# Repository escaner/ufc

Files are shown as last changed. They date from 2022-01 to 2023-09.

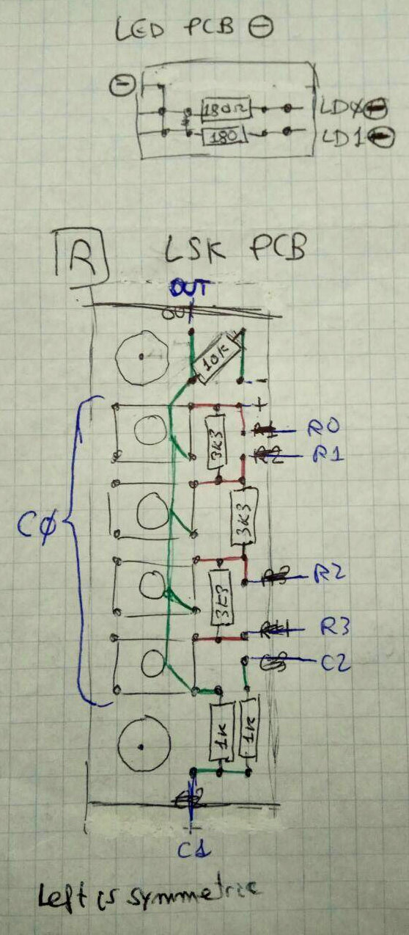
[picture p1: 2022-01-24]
doc/schematics/lsk-led-protobrds.jpg

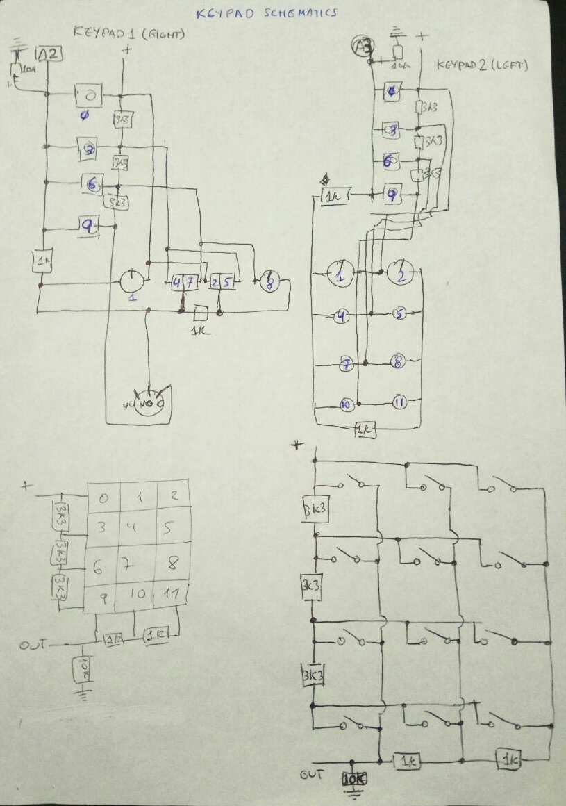
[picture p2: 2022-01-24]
doc/schematics/keypad.jpg

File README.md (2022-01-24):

https://github.com/escaner/ufc

UFC is an Arduino project to interface a button box made of button switches
and rotary encoders, LCD and LEDs, with a computer and identify itself as
a game controller sending DirectX events and communicating also via DCS-BIOS.

The core of the system is a Sparkfun Pro Micro or clone (small Arduino
Micro/Leonardo compatible). The switches are attached directly to the Arduino
analog input grids with resistors, while the encoders are directly attached
to digital pins and managed by the custom made REncoderAsync library.
The Joystick library interfaces with the computer and presents the Arduino
itself as a game controller.

This project requires the following libraries:
* https://github.com/dcs-bios/dcs-bios
* https://github.com/MHeironimus/ArduinoJoystickLibrary
* https://github.com/escaner/REncoder
* https://github.com/escaner/Switch
* https://github.com/fmalpartida/New-LiquidCrystal
* EEPROM

More info can be found in the doc directory, including schematics and
pictures.

Material used (most components were purchased on Aliexpress)
* 3D printer + PLA filament to make the case
* Adhesive vinyl with carbon fiber finish
* Paper printer, paper and glue for labels
* Hot glue gun + glue to stick the Pro Micro and other portoboard assemblies
* Soldering iron, solder, wires and other related tools
* Protoboard for LSK assembly, LED resistors and +/- hubs
* Dupont terminals (optional)
* 1 x USB A-microB cable
* 1 x Pro Micro 5V (Arduino/Sparkfun clone)
* 1 x Robotdyn 4x4 keypad module
* 1 x 2004 LCD display with I2C module
* Resistors for two matrices of buttons: 6 x 3.3K, 4 x 1K, 2 x 10K
* Resistors for LEDs: 2 x 180 Ohm (actual value depends on the LEDs)
* 1 x small momentary pushbutton (the red one)
* 2 x 15mm linear potentiometer 10K + knobs
* 8 x DIP tacile button 10mm 6x6 + 6mm caps
* 4 x rotary encoders with pushbutton + knobs
* 2 x 12mm 3-position momentary switch 3pin (SH T8014A-Z1)
* 6 x 12mm momentary pushbuttons
* 1 x 16mm momentary pushbutton with red LED for 5V
* 2 x 5mm green LEDs + housing
* 19 x M3 screws and nuts, serveral lengths (or saw to trim them!)
* 4 x adhesive rubber feet

To test whether the controller is recognized by a Linux the computer, you can
use the following command:

$ dmesg | grep Joystick

* Use the device name as follows to check the events sent to the computer:
$ jstest /dev/input/js1

Copyright (C) 2021-2022, Óscar Laborda

This file is part of UFC software.

UFC is free software: you can redistribute it and/or modify
it under the terms of the GNU General Public License as published by
the Free Software Foundation, either version 3 of the License, or
(at your option) any later version.

UFC is distributed in the hope that it will be useful,
but WITHOUT ANY WARRANTY; without even the implied warranty of
MERCHANTABILITY or FITNESS FOR A PARTICULAR PURPOSE.  See the
GNU General Public License for more details.

You should have received a copy of the GNU General Public License
along with UFC.  If not, see <https://www.gnu.org/licenses/>.

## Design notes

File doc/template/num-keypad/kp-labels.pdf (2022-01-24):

1

T-ILS

+

ABC SYS

2
N

ALOW

DEF NAV

3

+

GHI WP

4
W

STPT

JKLOSET

5

CRUS

MNOFPM

6
E

TIME

PQR PRV

7

MARK

STUFPLN

8
S

FIX

VWXMRK

9

A-CAL

YZ MSN

0

M-SEL · STEER

# CLR

MALF

# ENT

A/P

## IFF

## FUNC

## TCN

## LIST

## LTR

# A-AS

A-G

+
ON

A-G

SPCWPT

A-G

+

## ILS

A-A

MKUPDT

HCKPOS

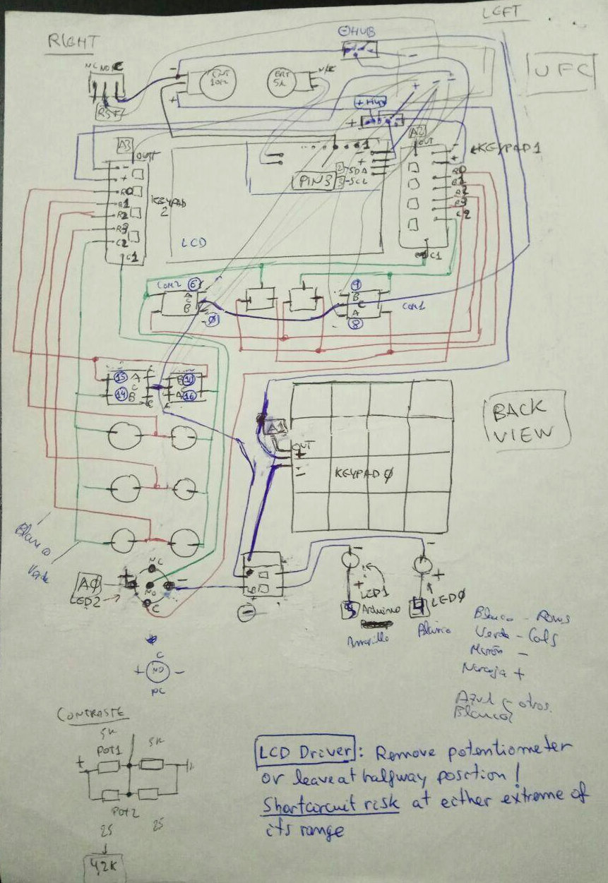
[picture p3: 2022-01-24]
doc/schematics/ufc.jpg

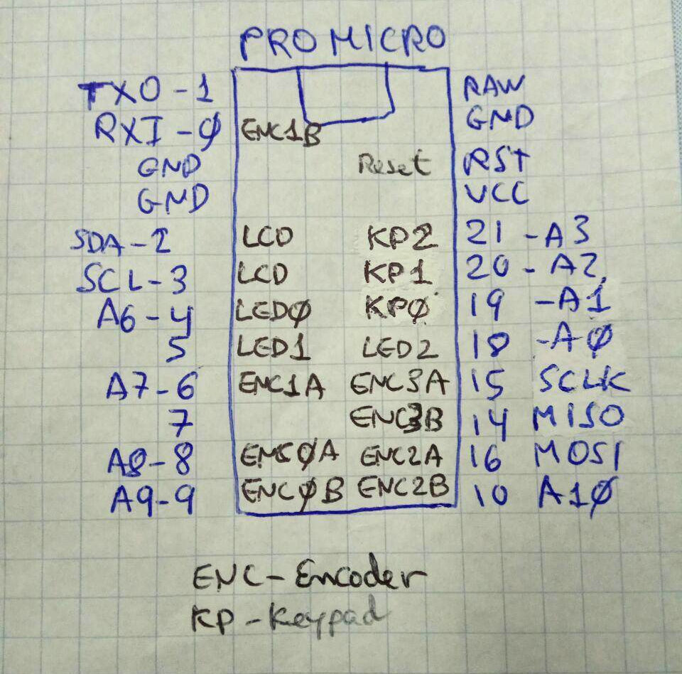
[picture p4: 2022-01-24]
doc/schematics/arduino-promicro.jpg

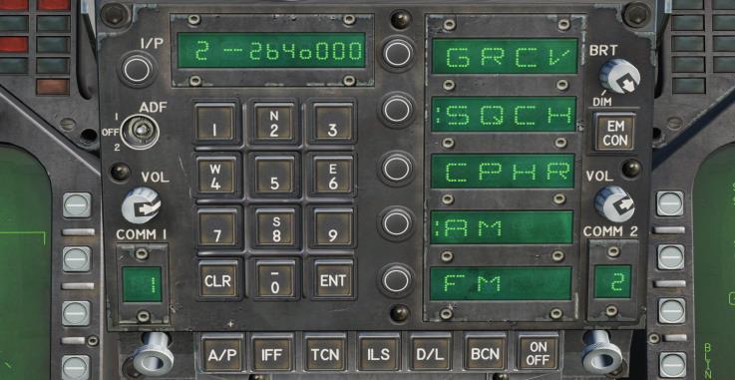
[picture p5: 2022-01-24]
doc/template/num-keypad/f18-ufc.jpg

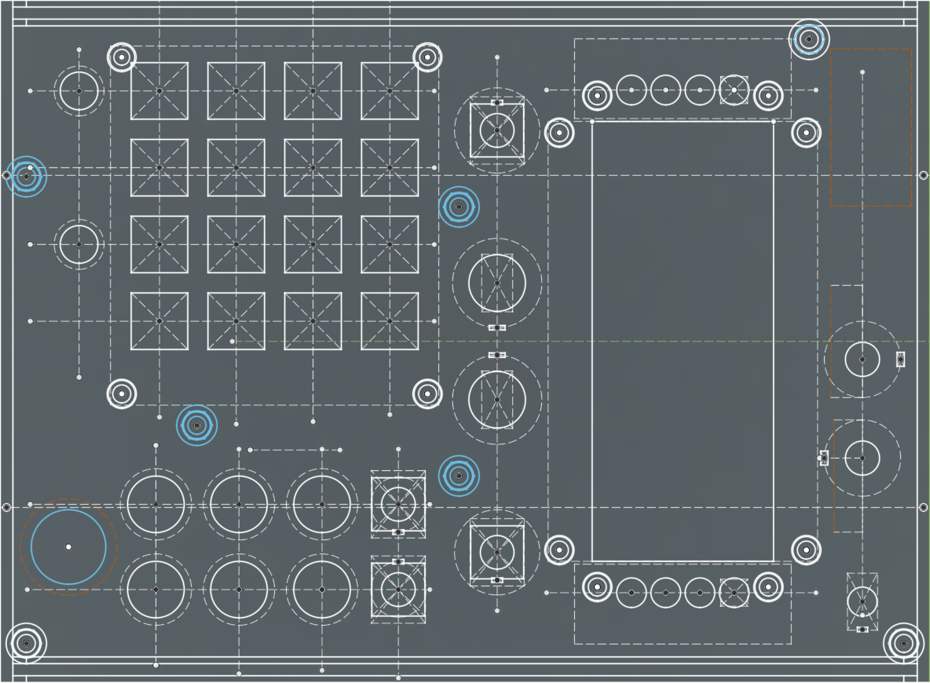
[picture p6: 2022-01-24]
doc/template/labels/shape.png

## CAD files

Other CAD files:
doc/case/ufc-panel.f3d

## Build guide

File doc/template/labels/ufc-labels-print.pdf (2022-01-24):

RESET

A

B

OP4

OP5

CDU LSK

IFEI

FCR

IFEI

CEN

CPL

OP1

OP2

OP3

IFEI

CDU LSK
HSD

MODE

## A-10 F/A-18

F-16 M2000

## COM1

## UHF⚫ HDG HDG

## FUEL QTY

HDG | CRS
DATA | SEL QTY | DIST
PG | -+
A/P | ALT HLD | ALT SEL APP

EFF INS

## MASTER ARM

## LST/R GUN RDY

## CAT I

## COM2

## ⚫V/UHF CRS CRS

WPT
SEQ

STEER
PTR

WPT

SEQ

VAD MODE

## CAUTION

TCN
TCN

NAV M

ILS
ILS

COM1

AUTO
ANCHR

DEC

WPT
STRPT

VISU

WPDSG

ALT
ALRT

A
MK

COM2

ENT

NORM WING

S T O R E S

1 2 3

DEST

REC

MRC

PREP

BAD

VAL

RANGE

RET

VAD -+ | VAD MODE

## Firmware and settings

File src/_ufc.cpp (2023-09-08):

#define DCSBIOS_DEFAULT_SERIAL

#include <stdint.h>
#include <EEPROM.h>
#include <Joystick.h>
#include <DcsBios.h>
#include "config.h"
#include "mode.h"
#include "switchpnl.h"
#include "displpnl.h"
#include "directx.h"


/*******************/
/* Local constants */
/*******************/

// Number of iterations processing switches per loop() call
constexpr uint16_t SWITCH_LOOP_CNT = 150U;

// EEPROM address where the default mode is stored
constexpr int EEPROM_MODE_ADDR = 0;


/** PRO MICRO pin connections **/

constexpr uint8_t PIN_LCD_EN = 2U;
constexpr uint8_t PIN_LCD_RW = 1U;
constexpr uint8_t PIN_LCD_RS = 0U;
constexpr uint8_t PIN_LCD_D4 = 4U;
constexpr uint8_t PIN_LCD_D5 = 5U;
constexpr uint8_t PIN_LCD_D6 = 6U;
constexpr uint8_t PIN_LCD_D7 = 7U;
constexpr uint8_t PIN_LCD_BL = 3U;

static const uint8_t PIN_ENCODER[NUM_ENC][ENC_NUM_PINS] =
{
  {  8,  9 }, // EncCom1
  {  6,  0 }, // EncCom2 (pin 7 does not work in my Pro Micro -> using 0 (RXI))
  { 16, 10 }, // EncLeft
  { 15, 14 }, // EncRight
};
static const uint8_t PIN_KP[NUM_KP] = { A1, A2, A3 };
static const uint8_t PIN_LED[NUM_LED] = { 4, 5, A0 };
// SDA: D2
// SCL: D3


/** Keypad constants **/

// Keypad where to read the mode at boot time
static const uint8_t KP_MODE = 0;


/** LCD **/

constexpr uint8_t LCD_ADDR = 0x27;

static const DisplPnl::LcdData_t LcdData =
{
  LCD_ADDR,
  PIN_LCD_EN,
  PIN_LCD_RW,
  PIN_LCD_RS,
  PIN_LCD_D4,
  PIN_LCD_D5,
  PIN_LCD_D6,
  PIN_LCD_D7,
  PIN_LCD_BL,
  POSITIVE
};


/* DCS-BIOS */

// Used in DCS BIOS messages in several modules
static const char _BIOS_MSG_HDG[] PROGMEM = { 'H', 'D', 'G' };
static const char _BIOS_MSG_CRS[] PROGMEM = { 'C', 'R', 'S' };
static const char _BIOS_ARG_INC_CHAR = '+';
static const char _BIOS_ARG_DEC_CHAR = '-';

constexpr uint8_t DCS_ACFTNAME_SZ = 24U;
constexpr unsigned int DCS_ACFTNAME_ADDR = 0x0000;

// A-10C
constexpr uint8_t A10C_CDUSP_SZ = 24U;
constexpr unsigned int A10C_CDUSP_ADDR = 0x1298;
constexpr uint8_t A10C_UHFFREQ_SZ = 7U;
constexpr unsigned int A10C_UHFFREQ_ADDR = 0x1180;
constexpr unsigned int A10C_UHFMODE_ADDR = 0x117c;
constexpr unsigned int A10C_UHFMODE_MASK = 0x0003;
constexpr unsigned int A10C_UHFMODE_SHIFT = 0U;
constexpr uint8_t A10C_UHFPSET_SZ = 2U;
constexpr unsigned int A10C_UHFPSET_ADDR = 0x1188;
constexpr uint8_t A10C_VAMFREQ_SZ = 7U;
constexpr unsigned int A10C_VAMFREQ_ADDR = 0x12de;
constexpr unsigned int A10C_VAMMODE_ADDR = 0x1186;
constexpr unsigned int A10C_VAMMODE_MASK = 0xc00;
constexpr unsigned int A10C_VAMMODE_SHIFT = 10U;
constexpr uint8_t A10C_VAMPSETSW_SZ = 2U;
constexpr unsigned int A10C_VAMPSETSW_ADDR = 0x118a;
constexpr uint8_t A10C_VFMFREQ_SZ = 7U;
constexpr unsigned int A10C_VFMFREQ_ADDR = 0x12e6;
constexpr unsigned int A10C_VFMMODE_ADDR = 0x1194;
constexpr unsigned int A10C_VFMMODE_MASK = 0x0180;
constexpr unsigned int A10C_VFMMODE_SHIFT = 7U;
constexpr uint8_t A10C_VFMPSETSW_SZ = 2U;
constexpr unsigned int A10C_VFMPSETSW_ADDR = 0x1196;
constexpr uint8_t A10C_TCNCHNL_SZ = 4U;
constexpr unsigned int A10C_TCNCHNL_ADDR = 0x1162;
constexpr unsigned int A10C_TCNMODE_ADDR = 0x1168;
constexpr unsigned int A10C_TCNMODE_MASK = 0x000e;
constexpr unsigned int A10C_TCNMODE_SHIFT = 1U;
constexpr uint8_t A10C_ILSFREQ_SZ = 6U;
constexpr unsigned int A10C_ILSFREQ_ADDR = 0x12d8;
constexpr unsigned int A10C_HSIHDG_ADDR = 0x104c;
constexpr unsigned int A10C_HSIHDG_MASK = 0xffff;
constexpr unsigned char A10C_HSIHDG_SHIFT = 0U;
constexpr unsigned int A10C_HSIHDGBUG_ADDR = 0x1052;
constexpr unsigned int A10C_HSIHDGBUG_MASK = 0xffff;
constexpr unsigned char A10C_HSIHDGBUG_SHIFT = 0U;
constexpr unsigned int A10C_HSICRS_ADDR = 0x1054;
constexpr unsigned int A10C_HSICRS_MASK = 0xffff;
constexpr unsigned char A10C_HSICRS_SHIFT = 0U;
constexpr unsigned int A10C_MASTERCAUTLT_ADDR = 0x1012;
constexpr unsigned int A10C_MASTERCAUTLT_MASK = 0x0800;
constexpr unsigned char A10C_MASTERCAUTLT_SHIFT = 11U;
constexpr unsigned int A10C_MASTERARMSW_ADDR = 0x10e8;
constexpr unsigned int A10C_MASTERARMSW_MASK = 0x000c;
constexpr unsigned char A10C_MASTERARMSW_SHIFT = 2U;
constexpr unsigned int A10C_GUNRDYLT_ADDR = 0x1026;
constexpr unsigned int A10C_GUNRDYLT_MASK = 0x8000;
constexpr unsigned char A10C_GUNRDYLT_SHIFT = 15U;

// F-16C
constexpr unsigned int F16C_DED_SZ = 29U;
constexpr unsigned int F16C_DEDLINE1_ADDR = 0x4500;
constexpr unsigned int F16C_DEDLINE2_ADDR = 0x451e;
constexpr unsigned int F16C_DEDLINE3_ADDR = 0x453c;
constexpr unsigned int F16C_DEDLINE4_ADDR = 0x455a;
constexpr unsigned int F16C_DEDLINE5_ADDR = 0x4578;
constexpr unsigned int F16C_FUELQTYKNOB_ADDR = 0x441e;
constexpr unsigned int F16C_FUELQTYKNOB_MASK = 0x0007;
constexpr unsigned char F16C_FUELQTYKNOB_SHIFT = 0U;
constexpr unsigned int F16C_FUELQTYKNOBTST_ADDR = 0x441c;
constexpr unsigned int F16C_FUELQTYKNOBTST_MASK = 0x4000;
constexpr unsigned char F16C_FUELQTYKNOBTST_SHIFT = 14U;
constexpr unsigned int F16C_FUELQTYAL_ADDR = 0x44e0;
constexpr unsigned int F16C_FUELQTYAL_MASK = 0xffff;
constexpr unsigned char F16C_FUELQTYAL_SHIFT = 0U;
constexpr unsigned int F16C_FUELQTYFR_ADDR = 0x44e2;
constexpr unsigned int F16C_FUELQTYFR_MASK = 0xffff;
constexpr unsigned char F16C_FUELQTYFR_SHIFT = 0U;
constexpr unsigned int F16C_FUELTOT100_ADDR = 0x44e8;
constexpr unsigned int F16C_FUELTOT100_MASK = 0xffff;
constexpr unsigned char F16C_FUELTOT100_SHIFT = 0U;
constexpr unsigned int F16C_FUELTOT1K_ADDR = 0x44e6;
constexpr unsigned int F16C_FUELTOT1K_MASK = 0xffff;
constexpr unsigned char F16C_FUELTOT1K_SHIFT = 0U;
constexpr unsigned int F16C_FUELTOT10K_ADDR = 0x44e4;
constexpr unsigned int F16C_FUELTOT10K_MASK = 0xffff;
constexpr unsigned char F16C_FUELTOT10K_SHIFT = 0U;
constexpr unsigned int F16C_MASTERCAUTLT_ADDR = 0x4476;
constexpr unsigned int F16C_MASTERCAUTLT_MASK = 0x0080;
constexpr unsigned char F16C_MASTERCAUTLT_SHIFT = 7U;
constexpr unsigned int F16C_MASTERARMSW_ADDR = 0x4424;
constexpr unsigned int F16C_MASTERARMSW_MASK = 0x0060;
constexpr unsigned char F16C_MASTERARMSW_SHIFT = 5U;
constexpr unsigned int F16C_STORESCFGSW_ADDR = 0x4400;
constexpr unsigned int F16C_STORESCFGSW_MASK = 0x0080;
constexpr unsigned char F16C_STORESCFGSW_SHIFT = 7U;

// F/A-18C
constexpr uint8_t FA18C_UFCSPSTR_SZ = 2U;
constexpr uint8_t FA18C_UFCSPNUM_SZ = 8U;
constexpr unsigned int FA18C_UFCSPSTR1_ADDR = 0x744e;
constexpr unsigned int FA18C_UFCSPSTR2_ADDR = 0x7450;
constexpr unsigned int FA18C_UFCSPNUM_ADDR = 0x7446;
constexpr uint8_t FA18C_UFCOPCUE_SZ = 1U;
constexpr unsigned int FA18C_UFCOPCUE1_ADDR = 0x7428;
constexpr unsigned int FA18C_UFCOPCUE2_ADDR = 0x742a;
constexpr unsigned int FA18C_UFCOPCUE3_ADDR = 0x742c;
constexpr unsigned int FA18C_UFCOPCUE4_ADDR = 0x742e;
constexpr unsigned int FA18C_UFCOPCUE5_ADDR = 0x7430;
constexpr uint8_t FA18C_UFCOPSTR_SZ = 4U;
constexpr unsigned int FA18C_UFCOPSTR1_ADDR = 0x7432;
constexpr unsigned int FA18C_UFCOPSTR2_ADDR = 0x7436;
constexpr unsigned int FA18C_UFCOPSTR3_ADDR = 0x743a;
constexpr unsigned int FA18C_UFCOPSTR4_ADDR = 0x743e;
constexpr unsigned int FA18C_UFCOPSTR5_ADDR = 0x7442;
constexpr uint8_t FA18C_UFCCOM_SZ = 2U;
constexpr unsigned int FA18C_UFCCOM1_ADDR = 0x7424;
constexpr unsigned int FA18C_UFCCOM2_ADDR = 0x7426;
constexpr uint8_t FA18C_IFEIFUEL_SZ = 6U;
constexpr unsigned int FA18C_IFEIFUELUP_ADDR = 0x748a;
constexpr unsigned int FA18C_IFEIFUELDN_ADDR = 0x7484;
constexpr uint8_t FA18C_IFEIBINGO_SZ = 5U;
constexpr unsigned int FA18C_IFEIBINGO_ADDR = 0x7462;
constexpr uint8_t FA18C_IFEIBINGOT_SZ = 1U;
constexpr unsigned int FA18C_IFEIBINGOT_ADDR = 0x74b6;
constexpr unsigned int FA18C_MASTERCAUTLT_ADDR = 0x7408;
constexpr unsigned int FA18C_MASTERCAUTLT_MASK = 0x0200;
constexpr unsigned char FA18C_MASTERCAUTLT_SHIFT = 9U;
constexpr unsigned int FA18C_MASTERARMSW_ADDR = 0x740c;
constexpr unsigned int FA18C_MASTERARMSW_MASK = 0x2000;
constexpr unsigned char FA18C_MASTERARMSW_SHIFT = 13U;
constexpr unsigned int FA18C_LTDRSW_ADDR = 0x74c4;
constexpr unsigned int FA18C_LTDRSW_MASK = 0x0100;
constexpr unsigned char FA18C_LTDRSW_SHIFT = 8U;

// M2000C

constexpr unsigned int M2000C_PCNLEFT_ADDR = 0x72ec;
constexpr uint8_t M2000C_PCNLEFT_SZ = 8U;
constexpr unsigned int M2000C_PCNRIGHT_ADDR = 0x72f6;
constexpr uint8_t M2000C_PCNRIGHT_SZ = 9U;
constexpr unsigned int M2000C_PCNDLEFT_ADDR = 0x7304;
constexpr uint8_t M2000C_PCNDLEFT_SZ = 2U;
constexpr unsigned int M2000C_PCNDRIGHT_ADDR = 0x7306;
constexpr uint8_t M2000C_PCNDRIGHT_SZ = 2U;
constexpr unsigned int M2000C_PCNDISPPREP_ADDR = 0x72f4;
constexpr uint8_t M2000C_PCNDISPPREP_SZ = 2U;
constexpr unsigned int M2000C_PCNDISPDEST_ADDR = 0x72ea;
constexpr uint8_t M2000C_PCNDISPDEST_SZ = 2U;
constexpr unsigned int M2000C_PCNMODEROT_ADDR = 0x72ea;
constexpr unsigned int M2000C_PCNSELROT_ADDR = 0x72c4;
constexpr unsigned int M2000C_PCNSELROT_MASK = 0xf000;
constexpr unsigned int M2000C_PCNSELROT_SHIFT = 12U;
constexpr unsigned int M2000C_PCNBTNLT_ADDR = 0x72d4;
constexpr unsigned int M2000C_PCNPREPBTNLT_MASK = 0x0100;
constexpr unsigned int M2000C_PCNDESTBTNLT_MASK = 0x0200;
constexpr unsigned int M2000C_PCNBADBTNLT_MASK = 0x0400;
constexpr unsigned int M2000C_PCNRECBTNLT_MASK = 0x0800;
constexpr unsigned int M2000C_PCNEFFBTNLT_MASK = 0x1000;
constexpr unsigned int M2000C_PCNINSBTNLT_MASK = 0x2000;
constexpr unsigned int M2000C_PCNVALBTNLT_MASK = 0x4000;
constexpr unsigned int M2000C_PCNMRCBTNLT_MASK = 0x8000;
constexpr unsigned char M2000C_PCNPREPBTNLT_SHIFT = 8U;
constexpr unsigned char M2000C_PCNDESTBTNLT_SHIFT = 9U;
constexpr unsigned char M2000C_PCNBADBTNLT_SHIFT = 10U;
constexpr unsigned char M2000C_PCNRECBTNLT_SHIFT = 11U;
constexpr unsigned char M2000C_PCNEFFBTNLT_SHIFT = 12U;
constexpr unsigned char M2000C_PCNINSBTNLT_SHIFT = 13U;
constexpr unsigned char M2000C_PCNVALBTNLT_SHIFT = 14U;
constexpr unsigned char M2000C_PCNMRCBTNLT_SHIFT = 15U;
constexpr unsigned int M2000C_PCNPANLT_ADDR = 0x72d0;
constexpr unsigned int M2000C_PCNPRETPANLT_MASK = 0x0400;
constexpr unsigned int M2000C_PCNALNPANLT_MASK = 0x0800;
constexpr unsigned int M2000C_PCNMIPPANLT_MASK = 0x1000;
constexpr unsigned int M2000C_PCNNDEGPANLT_MASK = 0x2000;
constexpr unsigned int M2000C_PCNSECPANLT_MASK = 0x4000;
constexpr unsigned int M2000C_PCNUNIPANLT_MASK = 0x8000;
constexpr unsigned char M2000C_PCNPRETPANLT_SHIFT = 10U;
constexpr unsigned char M2000C_PCNALNPANLT_SHIFT = 11U;
constexpr unsigned char M2000C_PCNMIPPANLT_SHIFT = 12U;
constexpr unsigned char M2000C_PCNNDEGPANLT_SHIFT = 13U;
constexpr unsigned char M2000C_PCNSECPANLT_SHIFT = 14U;
constexpr unsigned char M2000C_PCNUNIPANLT_SHIFT = 15U;
constexpr unsigned int M2000C_PCNMEMLT_ADDR = 0x72d8;
constexpr unsigned int M2000C_PCNM91MEMLT_MASK = 0x0200;
constexpr unsigned int M2000C_PCNM92MEMLT_MASK = 0x0400;
constexpr unsigned int M2000C_PCNM93MEMLT_MASK = 0x0800;
constexpr unsigned char M2000C_PCNM91MEMLT_SHIFT = 9U;
constexpr unsigned char M2000C_PCNM92MEMLT_SHIFT = 10U;
constexpr unsigned char M2000C_PCNM93MEMLT_SHIFT = 11U;
constexpr unsigned int M2000C_PANNELT_ADDR = 0x72aa;
constexpr unsigned char M2000C_PANNELT_SHIFT = 11U;
constexpr unsigned int M2000C_PANNEAMBERLT_MASK = 0x0800;
constexpr unsigned int M2000C_PANNEREDLT_MASK = 0x1000;


/*************/
/* Variables */
/*************/

static Mode WorkMode;

// Function to call for special procesing of input before sending DX events
// It depends on the WorkMode and returns true when standard processing should
// follow.
static bool (*pModeProcessEv)(const Event &Ev, const Directx::Event_t &EvDx) =
  nullptr;

// Switch panel: reads buttons (keypads) and rotary encoders
static SwitchPnl SwPnl(PIN_KP, PIN_ENCODER);

// LCD
static DisplPnl DiPnl(LcdData, PIN_LED);

// Joystick emulation object to send DirecX button events
static Joystick_ Joy(JOYSTICK_DEFAULT_REPORT_ID, JOYSTICK_TYPE_GAMEPAD,
  KP0_NUM_KEYS + KP1_NUM_KEYS + KP2_NUM_KEYS + NUM_ENC*2, 0,
  false, false, false, false, false, false, false, false, false, false, false);


/***********/
/* Methods */
/***********/

/* DCS-BIOS callbacks for A-10C */

/*
 *   Callback to update A-10C scratchpad.
 */
static void cbA10cCduScrpad(char *szValue)
{
  DiPnl.a10cScrpad(szValue);
}

/*
 *   Callback to update A-10C UHF radio frequency.
 */
static void cbA10cUhfFreq(char *szValue)
{
  DiPnl.a10cUhfFreq(szValue);
}

/*
 *   Callback to update A-10C UHF radio mode.
 */
static void cbA10cUhfMode(unsigned int Value)
{
  DiPnl.a10cUhfMode(Value);
}

/*
 *   Callback to update A-10C UHF radio preset channel.
 */
static void cbA10cUhfPset(char *szValue)
{
  DiPnl.a10cUhfPreset(szValue);
}

/*
 *   Callback to update A-10C VHF AM radio frequency.
 */
static void cbA10cVamFreq(char *szValue)
{
  DiPnl.a10cVamFreq(szValue);
}

/*
 *   Callback to update A-10C VHF AM radio mode.
 */
static void cbA10cVamMode(unsigned int Value)
{
  DiPnl.a10cVamMode(Value);
}

/*
 *   Callback to update A-10C VHF AM radio preset channel.
 */
static void cbA10cVamPset(char *szValue)
{
  DiPnl.a10cVamPreset(szValue);
}


/*
 *   Callback to update A-10C VHF FM radio frequency.
 */
static void cbA10cVfmFreq(char *szValue)
{
  DiPnl.a10cVfmFreq(szValue);
}

/*
 *   Callback to update A-10C VHF FM radio mode.
 */
static void cbA10cVfmMode(unsigned int Value)
{
  DiPnl.a10cVfmMode(Value);
}

/*
 *   Callback to update A-10C VHF FM radio preset channel.
 */
static void cbA10cVfmPset(char *szValue)
{
  DiPnl.a10cVfmPreset(szValue);
}

/*
 *   Callback to update A-10C TACAN radio channel.
 */
static void cbA10cTcnChannel(char *szValue)
{
  DiPnl.a10cTcnChannel(szValue);
}

/*
 *   Callback to update A-10C TACAN radio mode.
 */
static void cbA10cTcnMode(unsigned int Value)
{
  DiPnl.a10cTcnMode(Value);
}

/*
 *   Callback to update A-10C ILS radio frequency.
 */
static void cbA10cIlsFreq(char *szValue)
{
  DiPnl.a10cIlsFreq(szValue);
}

/*
 *   Callback to update A-10C HSI heading.
 *  Parameters:
 *  * Value: [0, 65535]
 */
static void cbA10cHsiHdg(unsigned int Value)
{
  DiPnl.a10cHdg(Value);
}

/*
 *   Callback to update A-10C HSI heading bug.
 *  Parameters:
 *  * Value: [0, 65535]
 */
static void cbA10cHsiHdgBug(unsigned int Value)
{
  DiPnl.a10cHdgBug(Value);
}

/*
 *   Callback to update A-10C HSI heading bug.
 *  Parameters:
 *  * Value: [0, 65535]
 */
static void cbA10cHsiCrs(unsigned int Value)
{
  DiPnl.a10cCrs(Value);
}

/*
 *   Callback to update A-10C Master Caution light.
 */
static void cbA10cMasterCautLt(unsigned int Value)
{
  DiPnl.a10cMasterCaut((uint8_t) Value);
}

/*
 *   Callback to update A-10C Master Arm switch position.
 */
static void cbA10cMasterArmSw(unsigned int Value)
{
  DiPnl.a10cMasterArm((uint8_t) Value);
}

/*
 *   Callback to update A-10C Gun Ready light.
 */
static void cbA10cGunReadyLt(unsigned int Value)
{
  DiPnl.a10cGunReady((uint8_t) Value);
}

/*
 *   Initializes A-10C mode.
 */
static void modeA10cInit()
{
  // Initializes display
  DiPnl.a10cStart();

  // Register special processing function
  pModeProcessEv = a10cProcessEv;

  // Register callbacks creating DCS-BIOS handlers in heap memory

  // CDU Scratchpad
  new DcsBios::StringBuffer<A10C_CDUSP_SZ>(A10C_CDUSP_ADDR, cbA10cCduScrpad);

  // Radios
  new DcsBios::StringBuffer<A10C_UHFFREQ_SZ>(
      A10C_UHFFREQ_ADDR, cbA10cUhfFreq);
  new DcsBios::IntegerBuffer(A10C_UHFMODE_ADDR, A10C_UHFMODE_MASK,
      A10C_UHFMODE_SHIFT, cbA10cUhfMode);
  new DcsBios::StringBuffer<A10C_UHFPSET_SZ>(
      A10C_UHFPSET_ADDR, cbA10cUhfPset);
  new DcsBios::StringBuffer<A10C_VAMFREQ_SZ>(
      A10C_VAMFREQ_ADDR, cbA10cVamFreq);
  new DcsBios::IntegerBuffer(A10C_VAMMODE_ADDR, A10C_VAMMODE_MASK,
      A10C_VAMMODE_SHIFT, cbA10cVamMode);
  new DcsBios::StringBuffer<A10C_VAMPSETSW_SZ>(
      A10C_VAMPSETSW_ADDR, cbA10cVamPset);
  new DcsBios::StringBuffer<A10C_VFMFREQ_SZ>(
      A10C_VFMFREQ_ADDR, cbA10cVfmFreq);
  new DcsBios::IntegerBuffer(A10C_VFMMODE_ADDR, A10C_VFMMODE_MASK,
      A10C_VFMMODE_SHIFT, cbA10cVfmMode);
  new DcsBios::StringBuffer<A10C_VFMPSETSW_SZ>(
      A10C_VFMPSETSW_ADDR, cbA10cVfmPset);
  new DcsBios::StringBuffer<A10C_TCNCHNL_SZ>(
      A10C_TCNCHNL_ADDR, cbA10cTcnChannel);
  new DcsBios::IntegerBuffer(A10C_TCNMODE_ADDR, A10C_TCNMODE_MASK,
      A10C_TCNMODE_SHIFT, cbA10cTcnMode);
  new DcsBios::StringBuffer<A10C_ILSFREQ_SZ>(
      A10C_ILSFREQ_ADDR, cbA10cIlsFreq);

  // Heading and course
  new DcsBios::IntegerBuffer(A10C_HSIHDG_ADDR, A10C_HSIHDG_MASK,
      A10C_HSIHDG_SHIFT, cbA10cHsiHdg);
  new DcsBios::IntegerBuffer(A10C_HSIHDGBUG_ADDR, A10C_HSIHDGBUG_MASK,
      A10C_HSIHDGBUG_SHIFT, cbA10cHsiHdgBug);
  new DcsBios::IntegerBuffer(A10C_HSICRS_ADDR, A10C_HSICRS_MASK,
      A10C_HSICRS_SHIFT, cbA10cHsiCrs);

  // LED lights
  new DcsBios::IntegerBuffer(A10C_MASTERCAUTLT_ADDR, A10C_MASTERCAUTLT_MASK,
      A10C_MASTERCAUTLT_SHIFT, cbA10cMasterCautLt);
  new DcsBios::IntegerBuffer(A10C_MASTERARMSW_ADDR, A10C_MASTERARMSW_MASK,
      A10C_MASTERARMSW_SHIFT, cbA10cMasterArmSw);
  new DcsBios::IntegerBuffer(A10C_GUNRDYLT_ADDR, A10C_GUNRDYLT_MASK,
      A10C_GUNRDYLT_SHIFT, cbA10cGunReadyLt);
}


/* DCS-BIOS callbacks for F-16C */

/*
 *   Callback to update F-16C DED Line 1.
 */
static void cbF16cDedLine1(char *szValue)
{
  DiPnl.f16cDed(0U, szValue);
}

/*
 *   Callback to update F-16C DED Line 2.
 */
static void cbF16cDedLine2(char *szValue)
{
  DiPnl.f16cDed(1U, szValue);
}

/*
 *   Callback to update F-16C DED Line 3.
 */
static void cbF16cDedLine3(char *szValue)
{
  DiPnl.f16cDed(2U, szValue);
}

/*
 *   Callback to update F-16C DED Line 4.
 */
static void cbF16cDedLine4(char *szValue)
{
  DiPnl.f16cDed(3U, szValue);
}

/*
 *   Callback to update F-16C DED Line 5.
 */
static void cbF16cDedLine5(char *szValue)
{
  DiPnl.f16cDed(4U, szValue);
}

/*
 *   Callback to update F-16C Fuel quantity selecion knob position changed in
 *  standard range.
 */
static void cbF16cFuelQtySelKnob(unsigned int Value)
{
  DiPnl.f16cFuelQtySelKnob((uint8_t) Value + (uint8_t) 1);
}

/*
 *   Callback to update F-16C Fuel quantity selecion knob position changed in
 *  test range.
 */
static void cbF16cFuelQtySelKnobTst(unsigned int Value)
{
  DiPnl.f16cFuelQtySelKnob((uint8_t) Value);
}

/*
 *   Callback to update F-16C Fuel quantity AL indicator.
 */
static void cbF16cFuelQtyIndAl(unsigned int Value)
{
  DiPnl.f16cFuelQtyIndicator(false, Value);
}

/*
 *   Callback to update F-16C Fuel quantity FR indicator.
 */
static void cbF16cFuelQtyIndFr(unsigned int Value)
{
  DiPnl.f16cFuelQtyIndicator(true, Value);
}

/*
 *   Callback to update F-16C hundreds of the fuel totalizer counter.
 */
static void cbF16cFuelTotCounter100(unsigned int Value)
{
  DiPnl.f16cFuelTotalizerHundreds(Value);
}

/*
 *   Callback to update F-16C thousands of the fuel totalizer counter.
 */
static void cbF16cFuelTotCounter1k(unsigned int Value)
{
  DiPnl.f16cFuelTotalizerThousands(false, Value);
}

/*
 *   Callback to update F-16C tens of thousands of the fuel totalizer counter.
 */
static void cbF16cFuelTotCounter10k(unsigned int Value)
{
  DiPnl.f16cFuelTotalizerThousands(true, Value);
}

/*
 *   Callback to update F-16C Master Caution light.
 */
static void cbF16cMasterCautLt(unsigned int Value)
{
  DiPnl.f16cMasterCaut((uint8_t) Value);
}

/*
 *   Callback to update F-16C Master Arm switch position.
 */
static void cbF16cMasterArmSw(unsigned int Value)
{
  DiPnl.f16cMasterArm((uint8_t) Value);
}

/*
 *   Callback to update F-16C stores configuration category switch position.
 */
static void cbF16cStoresCat(unsigned int Value)
{
  DiPnl.f16cStoresCat((uint8_t) Value);
}

/*
 *   Initializes F-16C mode.
 */
static void modeF16cInit()
{
  // Initializes display
  DiPnl.f16cStart();

  // Register special processing function
  pModeProcessEv = f16cProcessEv;

  // Tune encoder DX event delays for HDG/CRS and ICP Up/Dn
  SwPnl.setEncDelay(SwitchPnl::EncLeft, F16C_ICP_DX_DELAY_PR, DX_DELAY_RP);

  // Register callbacks creating DCS-BIOS handlers in heap memory

  // DED
  new DcsBios::StringBuffer<F16C_DED_SZ>(F16C_DEDLINE1_ADDR, cbF16cDedLine1);
  new DcsBios::StringBuffer<F16C_DED_SZ>(F16C_DEDLINE2_ADDR, cbF16cDedLine2);
  new DcsBios::StringBuffer<F16C_DED_SZ>(F16C_DEDLINE3_ADDR, cbF16cDedLine3);
  new DcsBios::StringBuffer<F16C_DED_SZ>(F16C_DEDLINE4_ADDR, cbF16cDedLine4);
  new DcsBios::StringBuffer<F16C_DED_SZ>(F16C_DEDLINE5_ADDR, cbF16cDedLine5);

  // Fuel
  new DcsBios::IntegerBuffer(F16C_FUELQTYKNOB_ADDR, F16C_FUELQTYKNOB_MASK,
      F16C_FUELQTYKNOB_SHIFT, cbF16cFuelQtySelKnob);
  new DcsBios::IntegerBuffer(F16C_FUELQTYKNOBTST_ADDR, F16C_FUELQTYKNOBTST_MASK,
      F16C_FUELQTYKNOBTST_SHIFT, cbF16cFuelQtySelKnobTst);
  new DcsBios::IntegerBuffer(F16C_FUELQTYAL_ADDR, F16C_FUELQTYAL_MASK,
      F16C_FUELQTYAL_SHIFT, cbF16cFuelQtyIndAl);
  new DcsBios::IntegerBuffer(F16C_FUELQTYFR_ADDR, F16C_FUELQTYFR_MASK,
      F16C_FUELQTYFR_SHIFT, cbF16cFuelQtyIndFr);
  new DcsBios::IntegerBuffer(F16C_FUELTOT100_ADDR, F16C_FUELTOT100_MASK,
      F16C_FUELTOT100_SHIFT, cbF16cFuelTotCounter100);
  new DcsBios::IntegerBuffer(F16C_FUELTOT1K_ADDR, F16C_FUELTOT1K_MASK,
      F16C_FUELTOT1K_SHIFT, cbF16cFuelTotCounter1k);
  new DcsBios::IntegerBuffer(F16C_FUELTOT10K_ADDR, F16C_FUELTOT10K_MASK,
      F16C_FUELTOT10K_SHIFT, cbF16cFuelTotCounter10k);

  // LED lights
  new DcsBios::IntegerBuffer(F16C_MASTERCAUTLT_ADDR, F16C_MASTERCAUTLT_MASK,
      F16C_MASTERCAUTLT_SHIFT, cbF16cMasterCautLt);
  new DcsBios::IntegerBuffer(F16C_MASTERARMSW_ADDR, F16C_MASTERARMSW_MASK,
      F16C_MASTERARMSW_SHIFT, cbF16cMasterArmSw);
  new DcsBios::IntegerBuffer(F16C_STORESCFGSW_ADDR, F16C_STORESCFGSW_MASK,
      F16C_STORESCFGSW_SHIFT, cbF16cStoresCat);
}


/* DCS-BIOS callbacks for F/A-18C */

/*
 *   Callback to update F/A-18C scratchpad's string 1.
 */
static void cbFa18cUfcScrpadStr1(char *szValue)
{
  DiPnl.fa18cScrpadStr1(szValue);
}

/*
 *   Callback to update F/A-18C scratchpad's string 2.
 */
static void cbFa18cUfcScrpadStr2(char *szValue)
{
  DiPnl.fa18cScrpadStr2(szValue);
}
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
void loop()
{
  // Check buttons
  processInput();

  // Process DCS-BIOS
  DcsBios::loop();
}

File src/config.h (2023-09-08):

#ifndef _CONFIG_H_
#define _CONFIG_H_

#include <stdint.h>


/*
 *   Define global constants for general program configuration.
 */

// Number of keypads
constexpr uint8_t NUM_KP = 3;

// Number of keys on each keypad
constexpr uint8_t KP0_NUM_KEYS = 16U;
constexpr uint8_t KP1_NUM_KEYS = 11U;
constexpr uint8_t KP2_NUM_KEYS = 12U;

// Number of rotary encoders
constexpr uint8_t NUM_ENC = 4;

// Number of Arduino pins per encoder
constexpr uint8_t ENC_NUM_PINS = 2;

// Number of LEDs as user interface output
constexpr uint8_t NUM_LED = 3;

// Dimensions of LCD
constexpr uint8_t LCD_ROWS =  4U;
constexpr uint8_t LCD_COLS = 20U;

// Delay between DirectX events
constexpr uint8_t DX_DELAY_PR = 5U;  // Delay press -> release (ms)
constexpr uint8_t DX_DELAY_RP = 5U;  // Delay release -> press (ms)
// Special delays for other modes
constexpr uint8_t F16C_ICP_DX_DELAY_PR = 80U;
//constexpr uint8_t F16C_HDGCRS_DX_DELAY_PR = 50U;

// Debounce time for keypads (us)
constexpr unsigned long KP_DEBOUNCE_TIME = 15000UL;


#endif  // _CONFIG_H_

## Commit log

2021-06-01 Modified encoder handling and call dcs-bios
2021-06-04 Case funcion naming
2021-12-12 Fixed M2000C PCN mode symbols
    [config.h, displpnl.cpp]
2022-01-24 Added crappy documentation
    [ufc-panel.f3d]
2022-08-15 M2000C UNI prefix: replace "+-" with "-+".
    [displpnl.cpp, displpnl.h, switchpnl.cpp]
2023-09-08 * Fix F-16C mode: event adresses, DED line sizes, fuel knob behaviour and CRS/HDG knob params changed. * KP debounce increased * KP2: Increased detection ranges
    [_ufc.cpp, config.h, switchpnl.cpp]
